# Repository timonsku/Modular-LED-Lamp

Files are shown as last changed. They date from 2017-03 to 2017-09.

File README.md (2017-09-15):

# Modular-LED-Lamp
<br />This work is licensed under a <a rel="license" href="http://creativecommons.org/licenses/by-sa/4.0/">Creative Commons Attribution-ShareAlike 4.0 International License</a>.

For more details see https://hackaday.io/project/20653-dirt-cheap-modular-led-lighting-system

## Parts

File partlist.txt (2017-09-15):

Partlist

Exported from Modular-LED-Lamp_driver_integrated.sch at 01.08.2017 19:53

EAGLE Version 8.2.2 Copyright (c) 1988-2017 Autodesk, Inc.

Assembly variant: 

Part      Value              Device             Package            Library               Sheet

C1        100uF              CAP_POLE           PANASONIC_E        SparkFun-Capacitors   1
D1                           DIODESMA-KIT       SMA-DIODE-KIT      SparkFun-DiscreteSemi 1
D2                           DIODESMA-KIT       SMA-DIODE-KIT      SparkFun-DiscreteSemi 1
GND-CLIP  FUSE-HOLDER-5X20MM FUSE-HOLDER-5X20MM FUSE-HOLDER-5X20MM timon-diverses        1
GND-CLIP1 FUSE-HOLDER-5X20MM FUSE-HOLDER-5X20MM FUSE-HOLDER-5X20MM timon-diverses        1
GND-CLIP2 FUSE-HOLDER-5X20MM FUSE-HOLDER-5X20MM FUSE-HOLDER-5X20MM timon-diverses        1
GND-CLIP3 FUSE-HOLDER-5X20MM FUSE-HOLDER-5X20MM FUSE-HOLDER-5X20MM timon-diverses        1
IC4                          PT4115             PT4115             PT4115                1
INDUCTOR                     MSS1260            MSS1260            inductor-coilcraft    1
LED-1     LUXEONSMD          LUXEONSMD          LUXEON             SparkFun-LED          1
LED-2     LUXEONSMD          LUXEONSMD          LUXEON             SparkFun-LED          1
LED-3     LUXEONSMD          LUXEONSMD          LUXEON             SparkFun-LED          1
LED-4     LUXEONSMD          LUXEONSMD          LUXEON             SparkFun-LED          1
PWM-CLIP  FUSE-HOLDER-5X20MM FUSE-HOLDER-5X20MM FUSE-HOLDER-5X20MM timon-diverses        1
PWM-CLIP1 FUSE-HOLDER-5X20MM FUSE-HOLDER-5X20MM FUSE-HOLDER-5X20MM timon-diverses        1
R1        2k                 RESISTOR1206       1206               SparkFun-Resistors    1
R2        0.3                RESISTOR1206       1206               SparkFun-Resistors    1
VCC-CLIP  FUSE-HOLDER-5X20MM FUSE-HOLDER-5X20MM FUSE-HOLDER-5X20MM timon-diverses        1
VCC-CLIP1 FUSE-HOLDER-5X20MM FUSE-HOLDER-5X20MM FUSE-HOLDER-5X20MM timon-diverses        1
VCC-CLIP2 FUSE-HOLDER-5X20MM FUSE-HOLDER-5X20MM FUSE-HOLDER-5X20MM timon-diverses        1
VCC-CLIP3 FUSE-HOLDER-5X20MM FUSE-HOLDER-5X20MM FUSE-HOLDER-5X20MM timon-diverses        1

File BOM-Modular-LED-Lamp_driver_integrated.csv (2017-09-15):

Qty | Value | Device | Package | Parts | Description | AliExpress Low Qty | AliExpress High Qty | Digikey
2 | 1A | DIODESMA-KIT | DO-214 (SMA) or SOD-123 | D1, D2 | Diode | https://www.aliexpress.com/item/100pcs-sma-1N5819-SMD-IN5819-1A-40V-do-214ac-Schottky-diode-ss14-free-shipping/32731083055.html | https://www.aliexpress.com/item/Free-Shipping-1000PCS-1N5819-IN5819-SS14-1A-40V-Barrier-Rectifiers-Diode-SMA/1947370006.html | https://www.digikey.de/product-detail/en/diodes-incorporated/B340A-13-F/B340A-FDICT-ND/725054
1 | 68uH | MSS1260 or similar | SMT D=7-10mm | INDUCTOR | SMT Power Inductor | https://www.aliexpress.com/item/25PCS-10-10-4MM-68UH-1-5A-SMD-104R-Shielded-Inductors/32786901262.html
1 | PT4115 | PT4115 | PT4115 | IC4 | 30V, 1.2A Step-down Constant Current Driver | https://www.aliexpress.com/item/10pcs-PT4115B89E-SOT89-5-PT4115-SOT-SMD-free-shipping/32720647869.html | https://www.aliexpress.com/item/200pcs-LOT-free-shipping-PT4115B89E-PT4115B-PT4115-4115-SOT-89-5-100-New-and-High-Quality/32359827347.html
1 | 0.3 | RESISTOR1206 | 1206 | R2 | Current Sense Resistor | https://www.aliexpress.com/item/1206-SMD-Resistor-1-0-3-ohm-5000pcs-lot/32308284240.html | https://www.aliexpress.com/item/1206-SMD-Resistor-1-0-3-ohm-5000pcs-lot/32308284240.html
1 | 100uF 35 or 50v (rec.) | CAP_POLE | PANASONIC_E (or D=6-8mm) | C1 | Capacitor Polarized | https://www.aliexpress.com/item/20pcs-lot-100uf-50V-SMD-Chip-Aluminum-Electrolytic-Capacitor-size-8mm-10mm/32326696621.html | https://www.aliexpress.com/item/100pcs-lot-100uf-50V-SMD-Chip-Aluminum-Electrolytic-Capacitor-size-8mm-10mm/32326692656.html
1 | 2k | RESISTOR1206 | 1206 | R1 | Resistor | https://www.aliexpress.com/item/1206-2K-ohm-5-1-4W-Resistor-3216-202-Chip-resistor-500Pcs-Lot/32600524262.html | https://www.aliexpress.com/item/Free-shipping-full-reel-5-1206-2K-2K-1-4W-SMD-Chip-Resistor-5000pcs-reel-YAGEO/32573670087.html
10 | FUSE-HOLDER-5X20MM | FUSE-HOLDER-5X20MM | FUSE-HOLDER-5X20MM | GND-CLIP, GND-CLIP1, GND-CLIP2, GND-CLIP3, PWM-CLIP, PWM-CLIP1, VCC-CLIP, VCC-CLIP1, VCC-CLIP2, VCC-CLIP3 | 5mm Fuse Holder | https://www.aliexpress.com/item/100pcs-lot-5x20-5-20mm-Fuse-Clips-fuse-block-fuse-holder-clip-DIP-PCB-Electronic-Fuse/32611331641.html | https://www.aliexpress.com/item/500pcs-lot-5x20-mm-Fuse-Clip-5-20-Fuse-Holder-Copper-with-Nickle-Plated-Fuse-Base/32652480461.html
4 | LUXEONSMD | LUXEONSMD | LUXEON | LED-1, LED-2, LED-3, LED-4 | Luxeon LED (3W rec. More efficent than 1W variant) | https://www.aliexpress.com/item/10pcs-Real-Full-Watt-CREE-1W-3W-High-Power-LED-lamp-Beads-Bulb-Diodes-SMD-110/32326397021.html | https://www.aliexpress.com/item/Free-shipping-50PCS-1W-3w-High-power-LED-Lamps-white-warm-white-30mil-45mil-Chips-high/32298464938.html
„ | „ | „ | „ | „ | Full Spectrum variant for plants | https://www.aliexpress.com/item/High-Power-LED-Chip-Deep-Red-LED-660nm-Plant-Grow-Light-1W-3W-5W-10W-20W/32633843531.html | https://www.aliexpress.com/item/100pcs-LED-3W-400nm-840nm-Full-Spectrum-Grow-Light-LED-Chip-Plant-Lights-Broad-Spectrum-Light/32593623542.html

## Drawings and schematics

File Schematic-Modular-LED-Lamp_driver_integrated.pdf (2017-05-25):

A

A

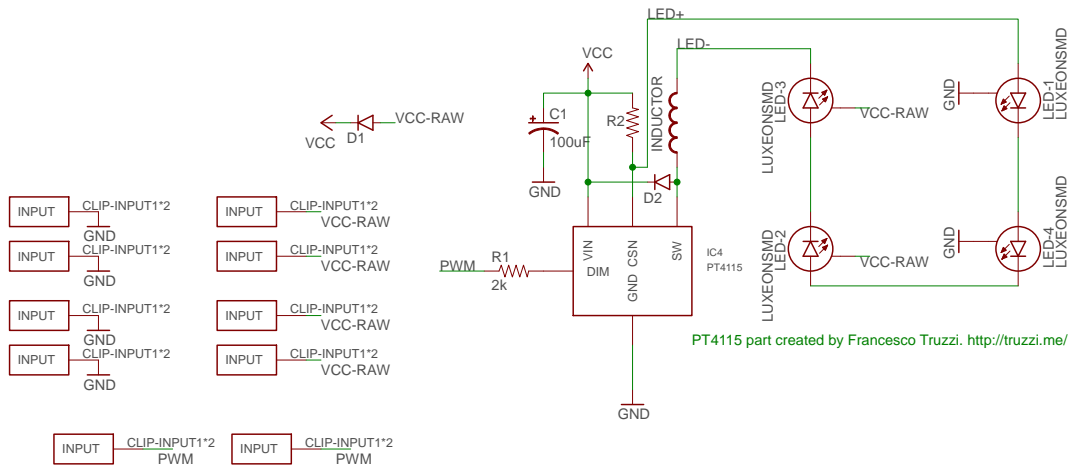
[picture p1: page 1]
LUXEONSMD; LUXEONSMD LUXEONSMD; LUXEONSMD GND; GND; VCC; LED-1; LED-2 LED-3; LED-4; INPUT; CLIP-INPUT1*2; VIN; CSN; DIM; INDUCTOR; LED-; LED+; PWM; VCC-RAW; A simple constant current; By Timon Skerutsch; Setup for 330mA per LED.; Modular-LED-Lamp_driver_integrated 25.05.2017 16:34; Sheet: 1/1

PT4115 part created by Francesco Truzzi. http://truzzi.me/

high efficiency LED driver.

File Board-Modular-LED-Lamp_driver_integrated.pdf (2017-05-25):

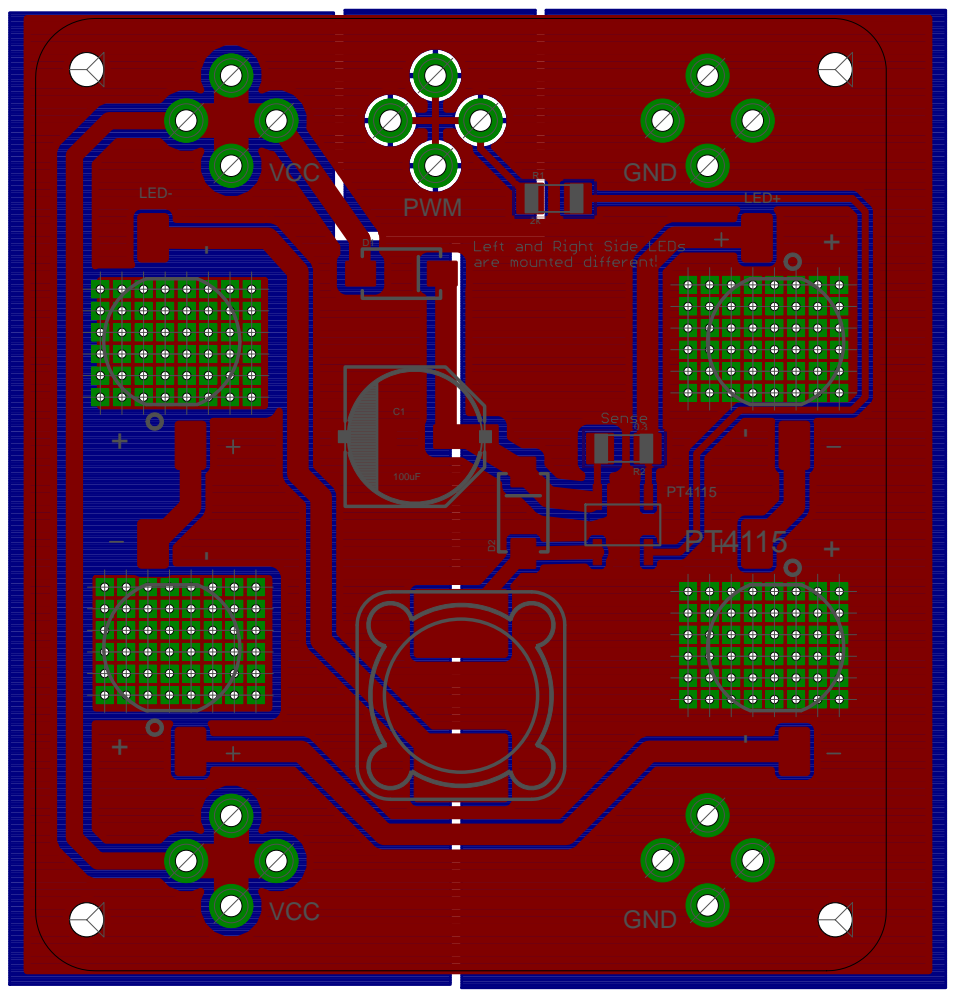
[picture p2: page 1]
LED-; LED+; GND; PWM; VCC

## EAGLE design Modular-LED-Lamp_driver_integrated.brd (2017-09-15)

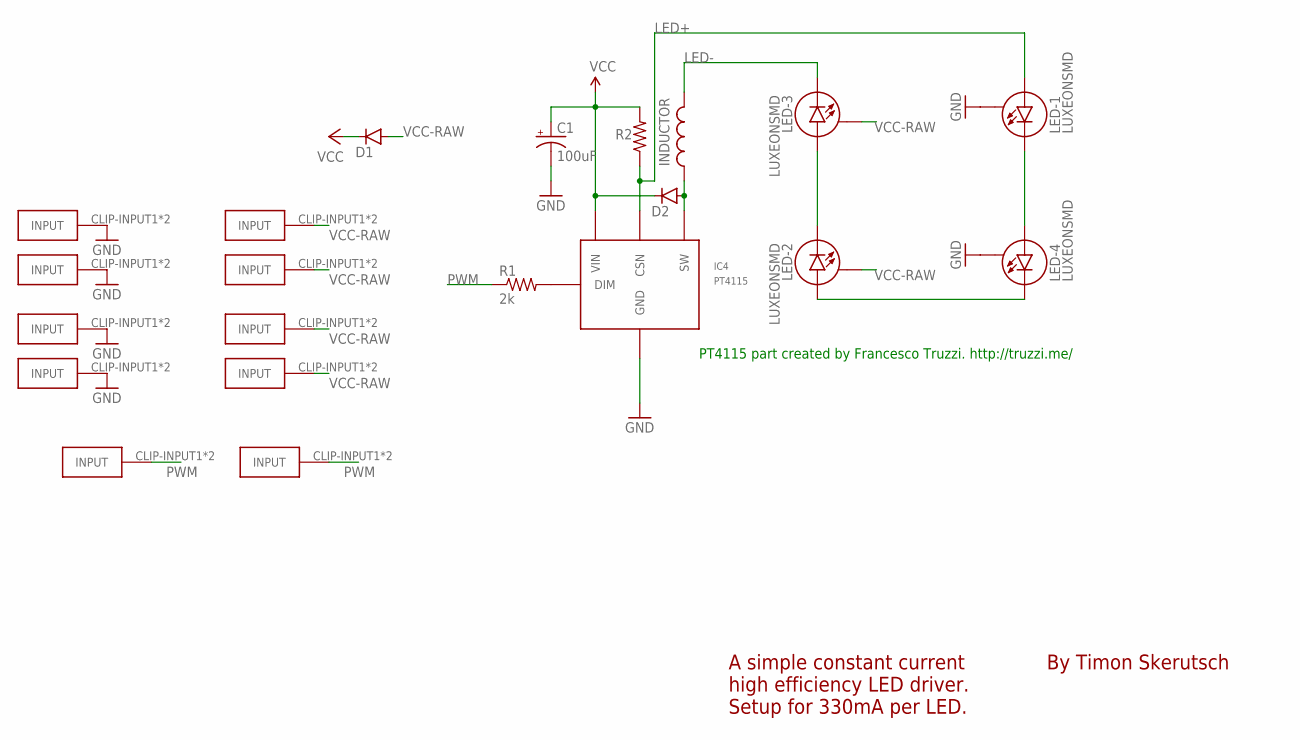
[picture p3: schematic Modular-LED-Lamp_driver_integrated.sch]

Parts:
C1: 100uF; PANASONIC_E
D1, D2: DIODESMA-KIT; SMA-DIODE-KIT
GND-CLIP, GND-CLIP1, GND-CLIP2, GND-CLIP3: FUSE-HOLDER-5X20MM
IC4: PT4115
INDUCTOR: MSS1260
LED-1, LED-2, LED-3, LED-4: LUXEONSMD; LUXEON
PWM-CLIP, PWM-CLIP1: FUSE-HOLDER-5X20MM
R1: 2k; 1206
R2: 0.3; 1206
VCC-CLIP, VCC-CLIP1, VCC-CLIP2, VCC-CLIP3: FUSE-HOLDER-5X20MM

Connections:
GND: C1.-, GND-CLIP.CLIP-INPUT1, GND-CLIP.CLIP-INPUT2, GND-CLIP1.CLIP-INPUT1, GND-CLIP1.CLIP-INPUT2, GND-CLIP2.CLIP-INPUT1, GND-CLIP2.CLIP-INPUT2, GND-CLIP3.CLIP-INPUT1, GND-CLIP3.CLIP-INPUT2, IC4.2 (GND), IC4.2A (GND), LED-1.S, LED-4.S
LED+: IC4.4 (CSN), LED-1.A, R2.1
LED-: INDUCTOR.P$1, LED-3.C
unnamed: D2.A, IC4.1 (SW), INDUCTOR.P$2
unnamed: LED-2.A, LED-4.C
unnamed: LED-2.C, LED-3.A
unnamed: LED-1.C, LED-4.A
unnamed: IC4.3 (DIM), R1.2
PWM: PWM-CLIP.CLIP-INPUT1, PWM-CLIP.CLIP-INPUT2, PWM-CLIP1.CLIP-INPUT1, PWM-CLIP1.CLIP-INPUT2, R1.1
VCC: C1.+, D1.C, D2.C, IC4.5 (VIN), R2.2
VCC-RAW: D1.A, LED-2.S, LED-3.S, VCC-CLIP.CLIP-INPUT1, VCC-CLIP.CLIP-INPUT2, VCC-CLIP1.CLIP-INPUT1, VCC-CLIP1.CLIP-INPUT2, VCC-CLIP2.CLIP-INPUT1, VCC-CLIP2.CLIP-INPUT2, VCC-CLIP3.CLIP-INPUT1, VCC-CLIP3.CLIP-INPUT2

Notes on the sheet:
PT4115 part created by Francesco Truzzi. http://truzzi.me/
By Timon Skerutsch
A simple constant current high efficiency LED driver. Setup for 330mA per LED.

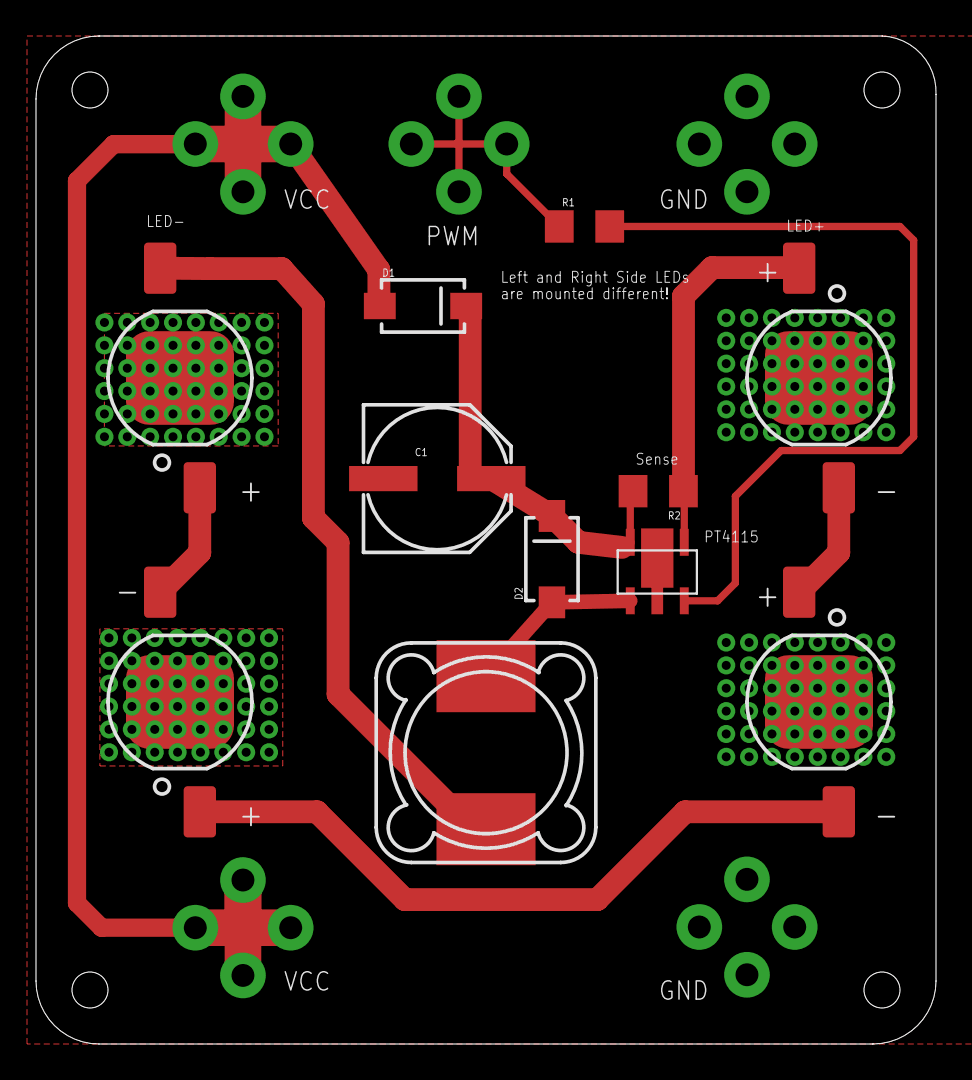
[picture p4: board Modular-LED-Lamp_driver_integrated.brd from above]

Board: 2 copper layers, 50.0 x 56.0 mm, 21 parts (1 on the bottom side), 11 nets.

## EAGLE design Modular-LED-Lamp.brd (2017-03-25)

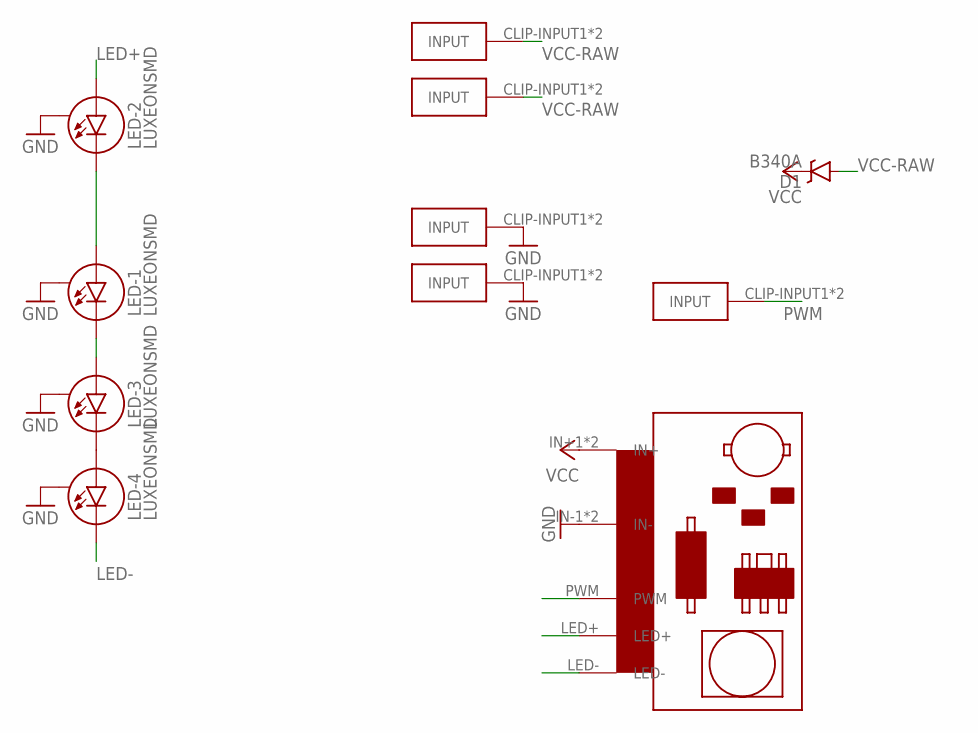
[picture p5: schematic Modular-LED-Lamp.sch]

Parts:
D1: B340A; SMA-DIODE
GND-CLIP, GND-CLIP2: GND; FUSE-HOLDER-5X20MM
LED-1, LED-2, LED-3, LED-4: LUXEONSMD; LUXEON
PWM-CLIP: FUSE-HOLDER-5X20MM
U$1: PT4115-MODULE
VCC-CLIP, VCC-CLIP2: FUSE-HOLDER-5X20MM

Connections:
GND: GND-CLIP.CLIP-INPUT1, GND-CLIP.CLIP-INPUT2, GND-CLIP2.CLIP-INPUT1, GND-CLIP2.CLIP-INPUT2, LED-1.S, LED-2.S, LED-3.S, LED-4.S, U$1.IN-1 (IN-), U$1.IN-2 (IN-)
LED+: LED-2.A, U$1.LED+
LED-: LED-4.C, U$1.LED-
unnamed: LED-1.C, LED-3.A
unnamed: LED-3.C, LED-4.A
unnamed: LED-1.A, LED-2.C
PWM: PWM-CLIP.CLIP-INPUT1, PWM-CLIP.CLIP-INPUT2, U$1.PWM
VCC: D1.C, U$1.IN+1 (IN+), U$1.IN+2 (IN+)
VCC-RAW: D1.A, VCC-CLIP.CLIP-INPUT1, VCC-CLIP.CLIP-INPUT2, VCC-CLIP2.CLIP-INPUT1, VCC-CLIP2.CLIP-INPUT2

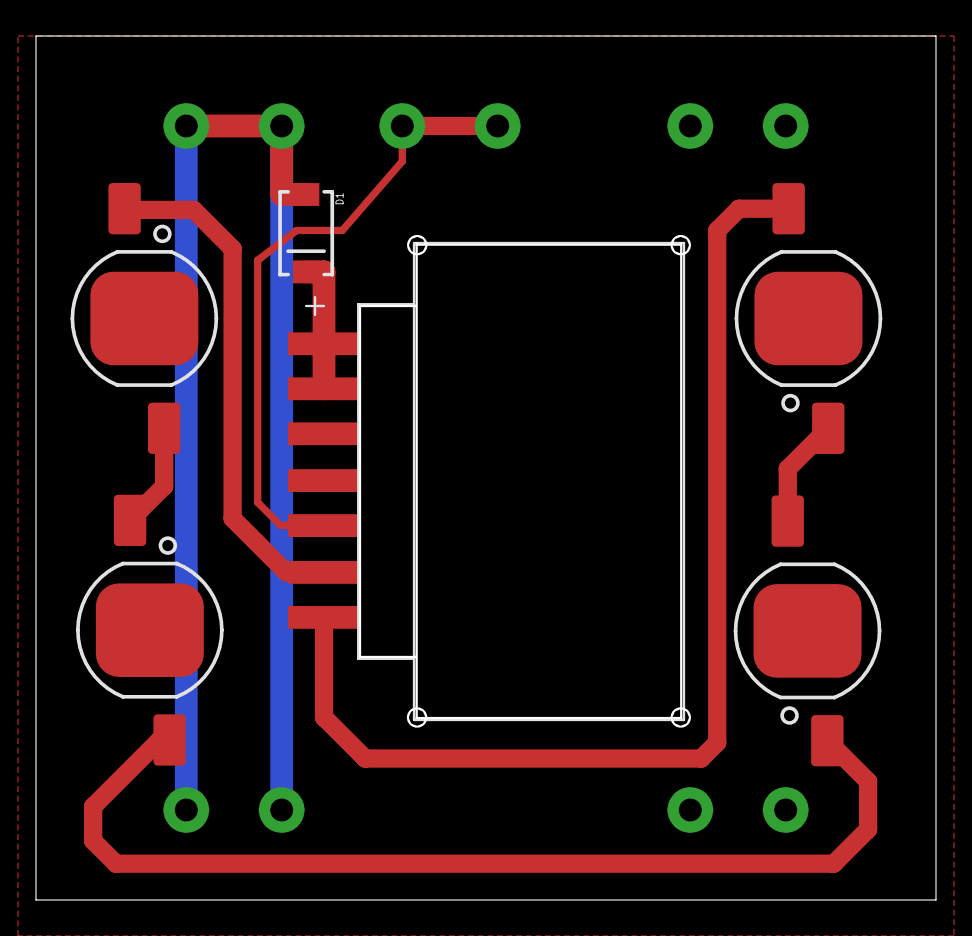
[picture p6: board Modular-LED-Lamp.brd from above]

Board: 2 copper layers, 50.0 x 48.0 mm, 11 parts (0 on the bottom side), 9 nets.

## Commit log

2017-04-16 changed outline to be bigger to disspate more heat, added footprint for 90° turned fuse holders, rounded edges
    [Modular-LED-Lamp_driver_integrated.brd, Modular-LED-Lamp_driver_integrated.sch]
2017-05-01 updated integrated driver module to be 1W instead of 3W
    [Modular-LED-Lamp_driver_integrated.brd, Modular-LED-Lamp_driver_integrated.sch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]
2017-05-01 updated gitignore for gerber related files
2017-05-19 fixed issued with PWM rod causing short circuit when two boards are mounted with one being reversed. Added PDF for schematic and board.
    [Modular-LED-Lamp_driver_integrated.brd, Modular-LED-Lamp_driver_integrated.sch]
2017-05-25 Added BOM, updated schematic and board for integrated variant
    [BOM-Modular-LED-Lamp_driver_integrated.csv, Modular-LED-Lamp_driver_integrated.brd, Modular-LED-Lamp_driver_integrated.sch]
2017-09-15 Changed license to CC-BY-SA
    [BOM-Modular-LED-Lamp_driver_integrated.csv, Modular-LED-Lamp_driver_integrated.brd, Modular-LED-Lamp_driver_integrated_bom.csv]

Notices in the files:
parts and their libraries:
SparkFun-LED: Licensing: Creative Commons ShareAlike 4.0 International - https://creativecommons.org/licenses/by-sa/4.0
